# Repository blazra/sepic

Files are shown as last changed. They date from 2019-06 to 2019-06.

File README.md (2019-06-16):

# SEPIC
SEPIC converter design as a school project

Schematic: [kicad/sepic/sepic.pdf](kicad/sepic/sepic.pdf)  
Write-up in czech: [SEPIC_Radovan_Blazek.pdf](SEPIC_Radovan_Blazek.pdf)  
LibreOffice sheet with measured data: [Measurements.ods](Measurements.ods)  
LibreOffice sheet with component values calculations as per LT8710 datasheet: [SEPIC_calculations.ods](SEPIC_calculations.ods)  
LT8710 datasheet: https://www.analog.com/media/en/technical-documentation/data-sheets/8710f.pdf

Bugs in Rev. 1:
- SYNC input of the LT8710 is not pulled to GND

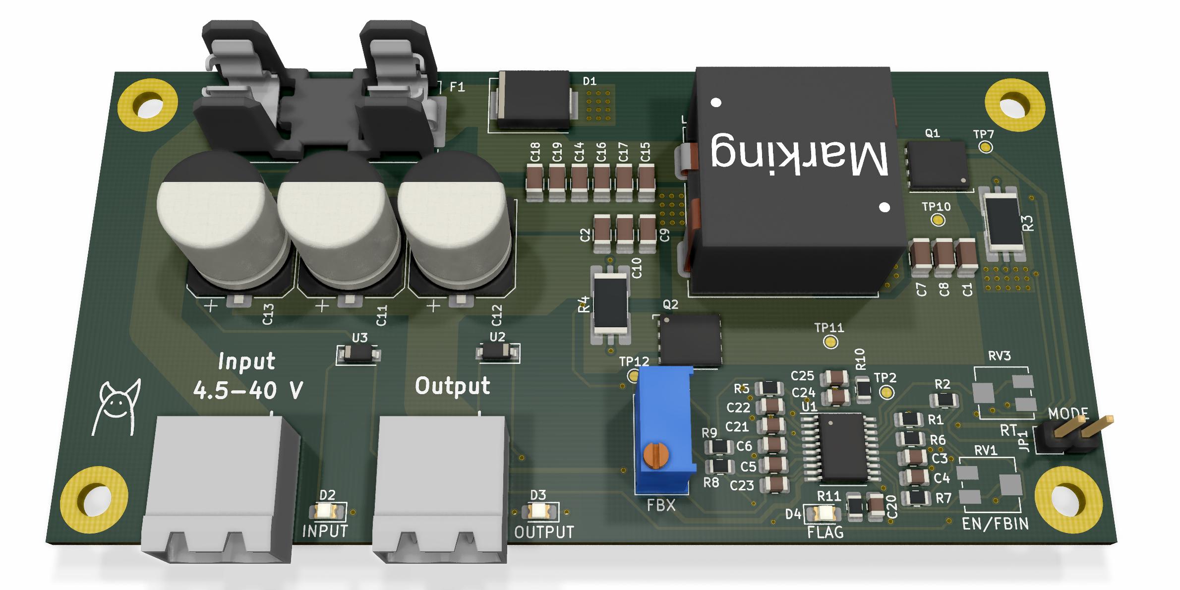
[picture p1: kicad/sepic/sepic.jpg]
3D render
3D render: 

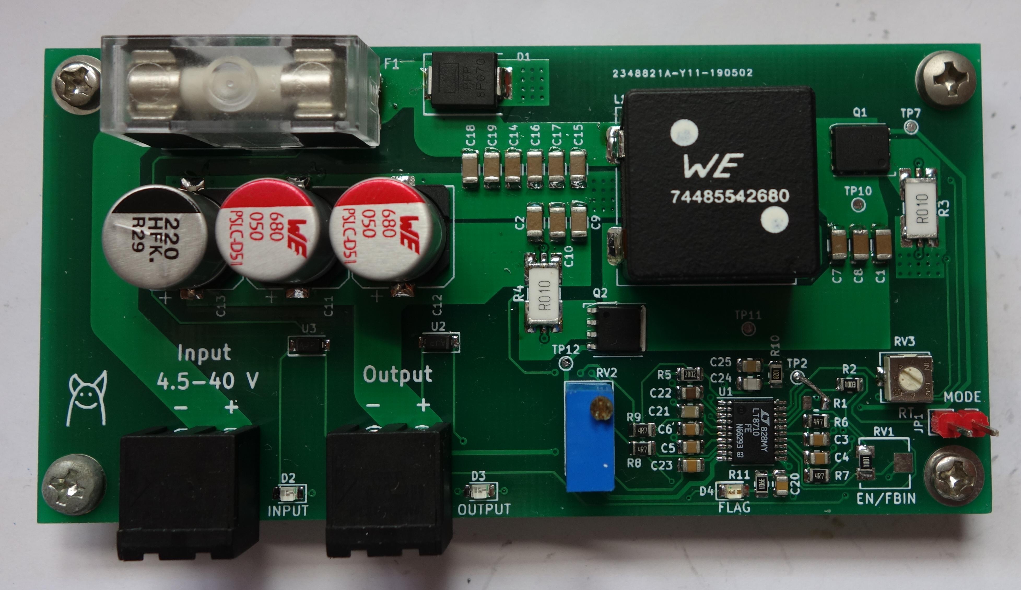
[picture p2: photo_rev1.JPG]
Photo of the finished board:

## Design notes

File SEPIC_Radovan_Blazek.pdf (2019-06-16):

# SEPIC

2019

## Radovan Blažek

## Semestrální práce na předmět B2M34VKE


## Obsah

1 Zadání | 2
2 Výpočet obvodových prvků | 2
3 Schéma | 2
4 Layout | 4
5 Měření | 5
6 Závěr | 7

## 1 Zadání

Navrhněte synchronní SEPIC, parametry: VIN = 6 V–28 V, VOUT = 15 V, POUT = 8W.

## 2 Výpočet obvodových prvků

Podle datasheetu řídícího obvodu LT8710: https://www.analog.com/media/en/technical-documentation/data-sheets/8710f.pdf

VIN(MIN) = 6 V
VOUT = 15 V
IOUT = 0.533 A
f = 500 kHz

DC MAX ≈

VOUT
VIN(MIN) + VOUT
; (Maximální střída) | DC MAX ≈ 0.714

VCSPN ≈ 37.5 mV ; (Určuje max. proud cívkou.)

RSENSE1 ≤ 0.58

VCSPN

IOUT

(1 − DC MAX) | RSENSE1 ≤ 0.0137 Ω → RSENSE1 = 10 mΩ

RSENSE2 ≤

0.05
1.6 · IOUT

RSENSE2 ≤ 0.0590 Ω → RSENSE2 = 10 mΩ

LTYP =

RSENSE1 · VOUT
12.5m · f

·

VIN(MIN)
VIN(MIN) + VOUT

LTYP = 6.86 µH

LMAX =

RSENSE1 · VOUT
40m · f

·

1 −

VIN(MIN)

VOUT 2

!
LMAX = 17.14 µH

LMIN =

RSENSE1 · VOUT
5m · f

·

VIN(MIN)
VIN(MIN) + VOUT

LMIN = 6.3 µH

C1 ≥ 10 µF

COUT ≥

IOUT · DCMAX
f · 0.005 · VOUT

COUT ≥ 10.1 µF

CIN ≥

DCMAX
8 · L · f

2 · 0.005

CIN ≥ 10.42 µF

CIMON ≥

100µ · DCMAX
0.005 · f

CIMON ≥ 28.57 nF

RFBX =

VOUT − 1.213 V
83.7 µA

RFBX = 164 719 Ω

RT =

35880
f
− 1 ; f in kHz and RT in kΩ | RT = 70.760 kΩ

## 3 Schéma

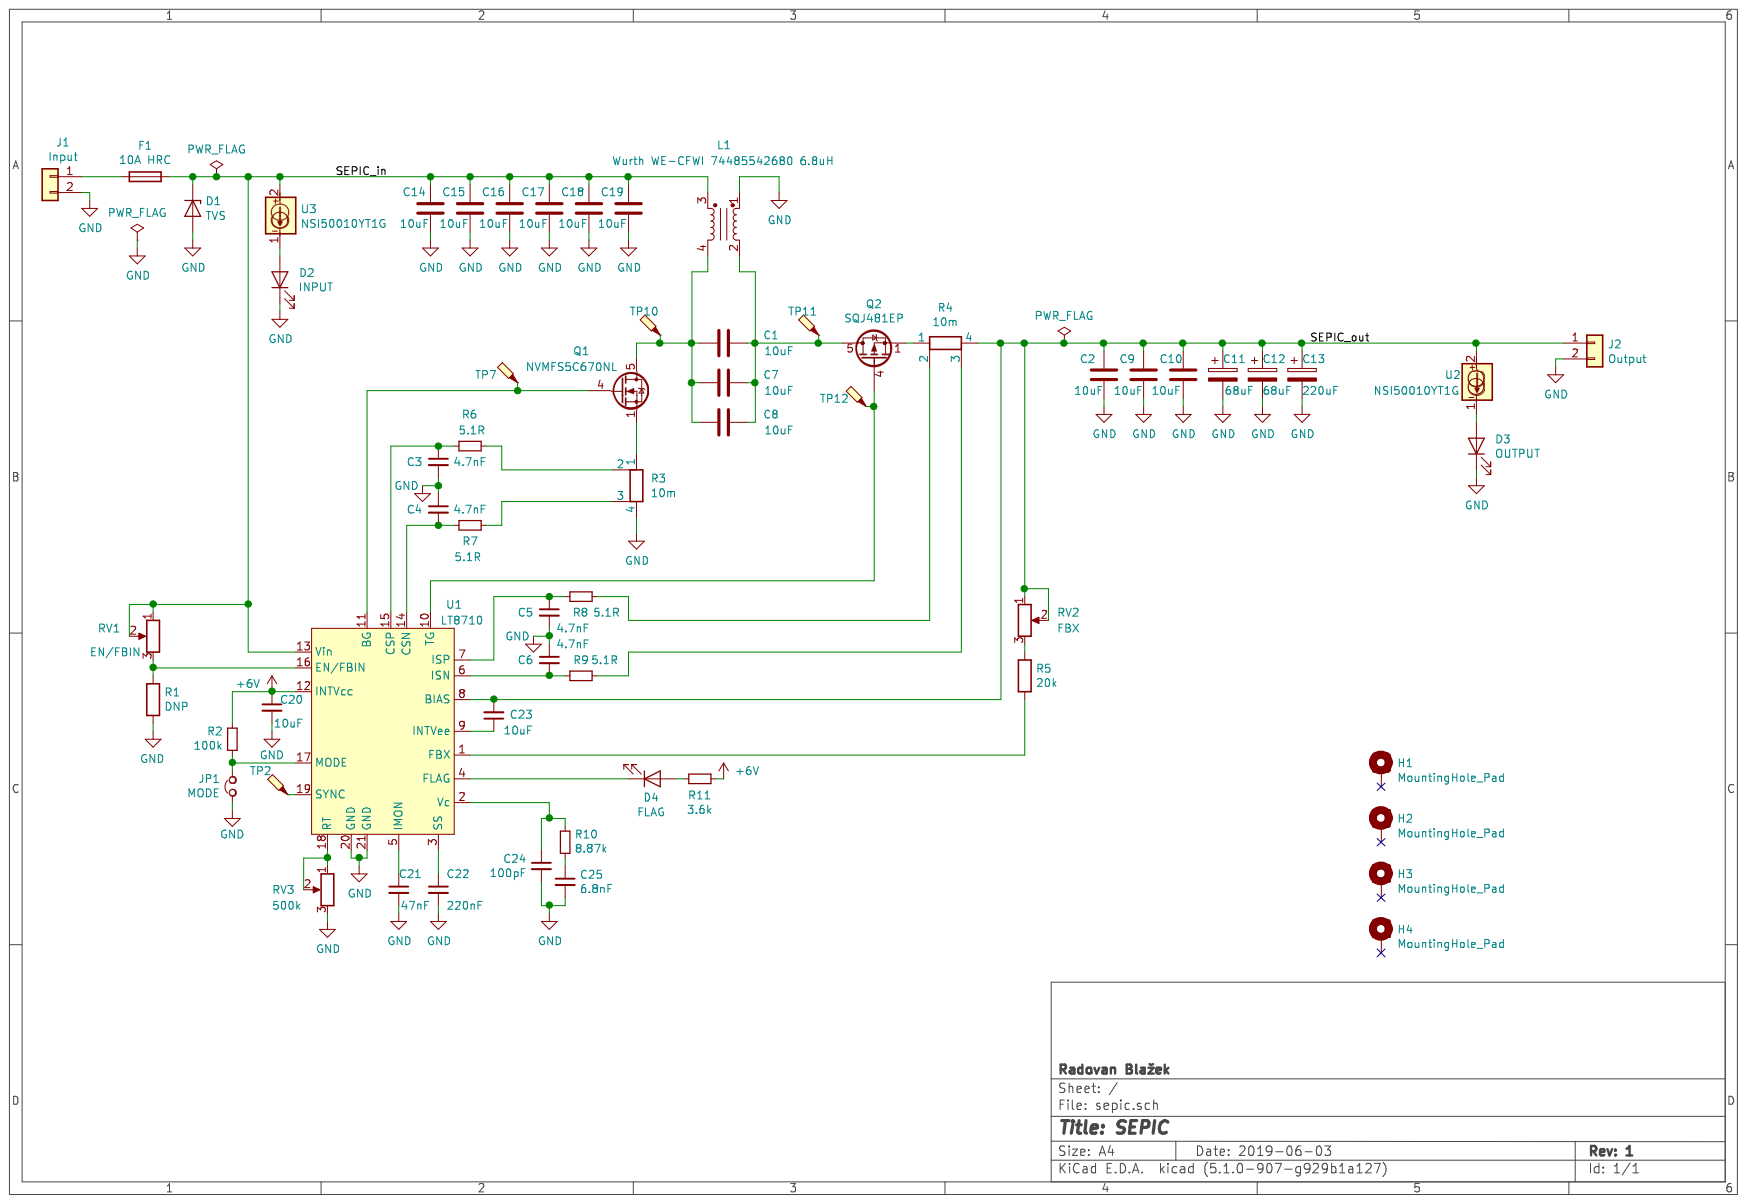
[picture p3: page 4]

## 4 Layout

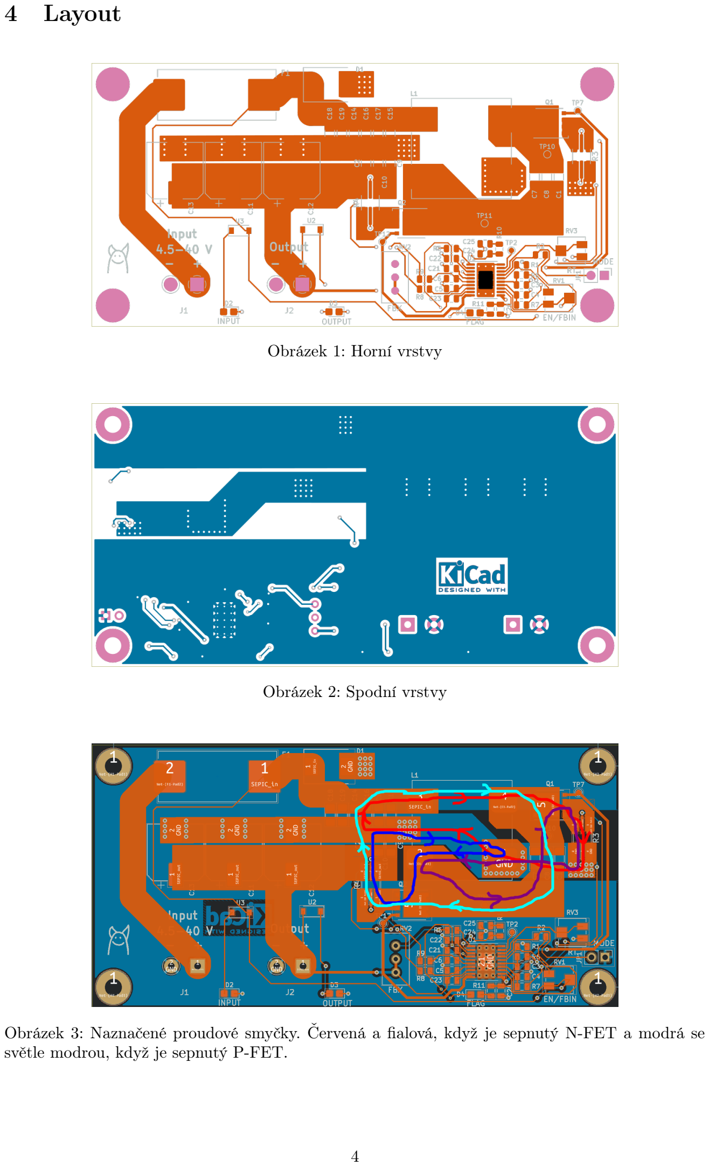
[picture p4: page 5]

Obrázek 1: Horní vrstvy

Obrázek 2: Spodní vrstvy

Obrázek 3: Naznačené proudové smyčky. Červená a fialová, když je sepnutý N-FET a modrá se světle modrou, když je sepnutý P-FET.

## 5 Měření

### 5.1 Použité přístroje

Zdroj | HP E3630 | (Vstupní napětí a proud do měniče)
Voltmetr | Keithley 2000 | (Výstupní napětí z měniče)
Elektronická zátěž | Chroma 63106 | (Výstupní proud z měniče)
Osciloskop | LeCroy WaveRunner 6050A | (Průběhy výstupního napětí)

### 5.2 Výsledky

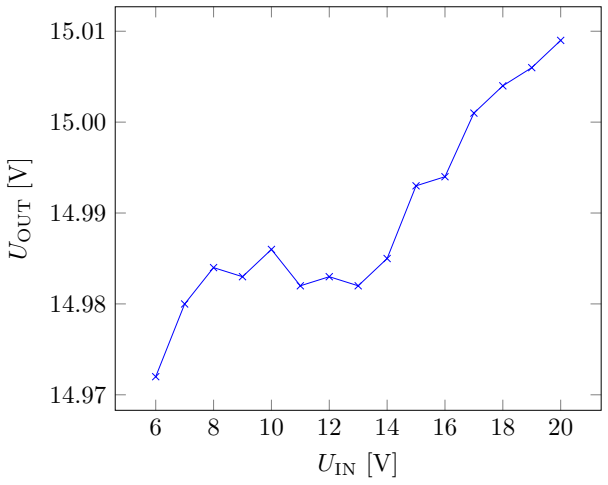
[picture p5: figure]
UIN [V]; UOUT [V]

Obrázek 4: Změna výstupního napětí v závislosti na vstupním napětí

LNR = 2.643 mV/V

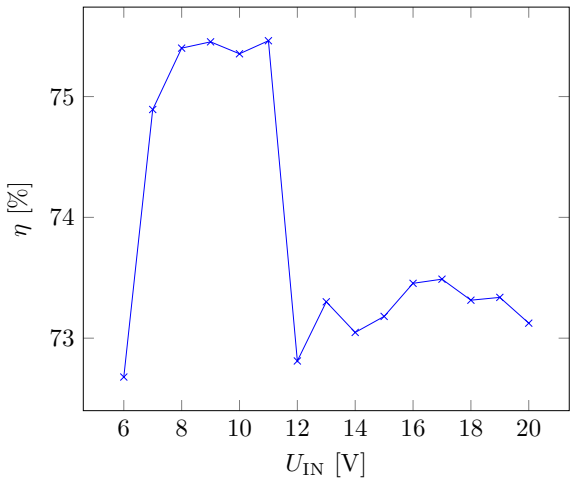
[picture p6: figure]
UIN [V]

Obrázek 5: Účinnost v závislosti na vstupním napětí

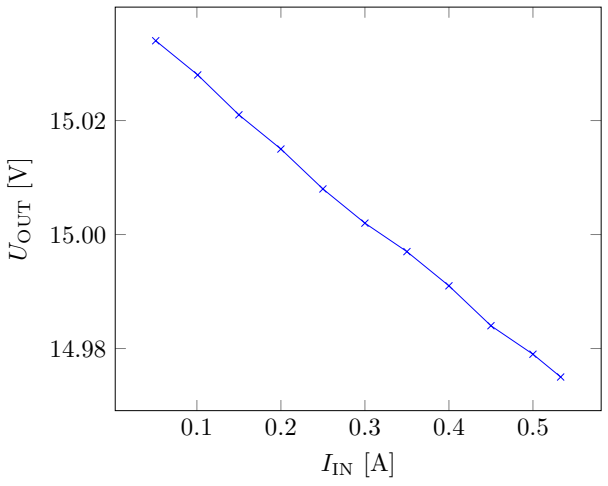
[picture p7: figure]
IIN [A]; UOUT [V]

Obrázek 6: Výstupní napětí v závislosti na výstupním proudu

LOR = −122.4 mV/A

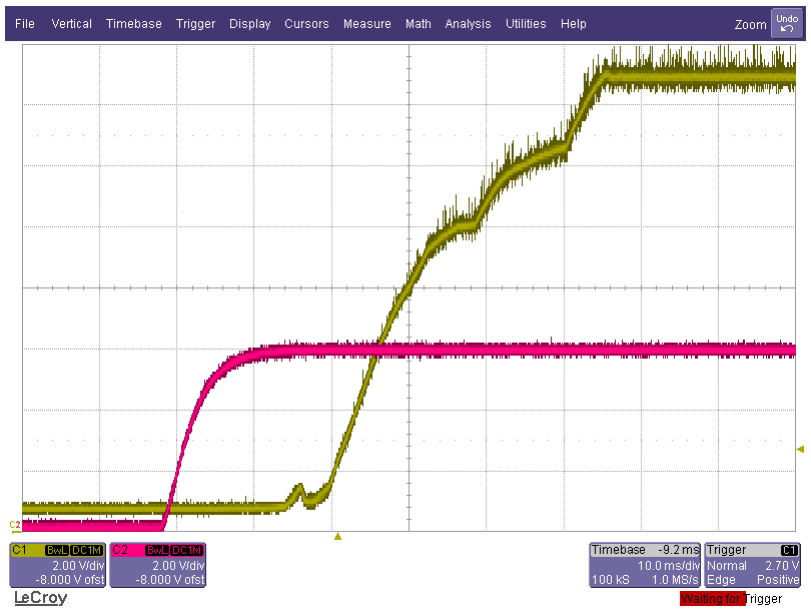
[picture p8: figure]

Obrázek 7: Start měniče. C2 (červená): vstup do měniče, C1 (žlutá): výstup z měniče. Nastavení osciloskopu: omezení šířky pásma na 20 MHz.

Na obrázku 8 je průběh výstupního napětí při skokové změně proudu do zátěže z 10 mA na 533 mA.

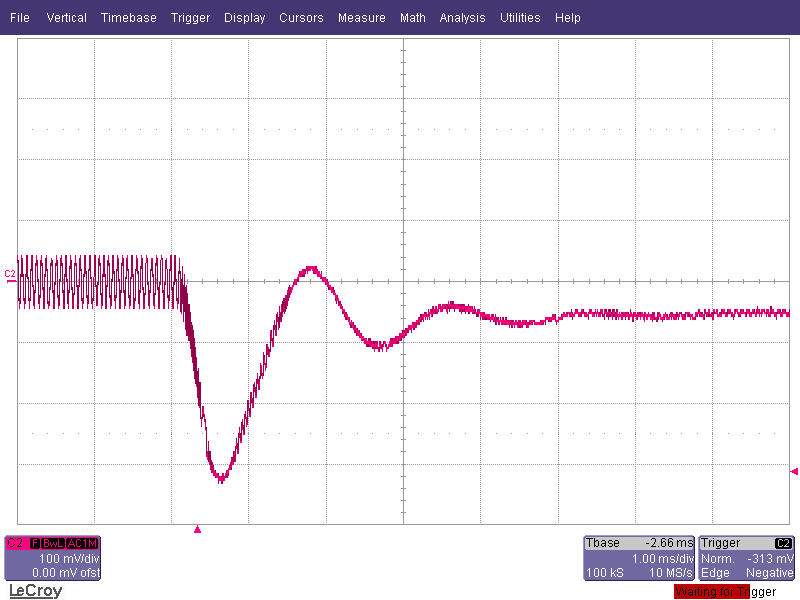
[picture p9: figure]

Obrázek 8: Odezva na skokovou změnu proudu do zátěže. Nastavení osciloskopu: omezení šířky pásma na 20 MHz a mód akvizice s vysokým rozlišením (oversampling).

## 6 Závěr

Částečné rozdělení zemní plochy byla rozhodně chyba, nicméně, nepodařilo se mi naměřit žádnou změnu v chování měniče při spojení všech částí zemní plochy v jednu souvislou.
Zásadní nedostatek je absence místa na PCB, kam by šla připojit proudová sonda na měření proudu cívkou.
Na výstupu měniče jsou veliké napěťové špičky vznikající při vypínání hlavního N-kanálového MOSFETu.
I přes zmíněné nedostatky měnič funguje a zvládá zatížení 8 W při vstupním napětí 6-20 V. Zadání bylo vstupní napětí až 28 V, ale při měření jsem měl k dispozici pouze zdroj do 20 V. Můj předpoklad je, že měnič by měl být funkční i v rozsahu 20-28 V.

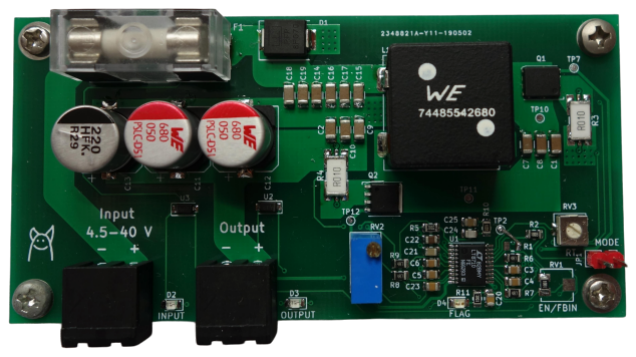
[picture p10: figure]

Obrázek 9: Fotografie osazeného desky měniče

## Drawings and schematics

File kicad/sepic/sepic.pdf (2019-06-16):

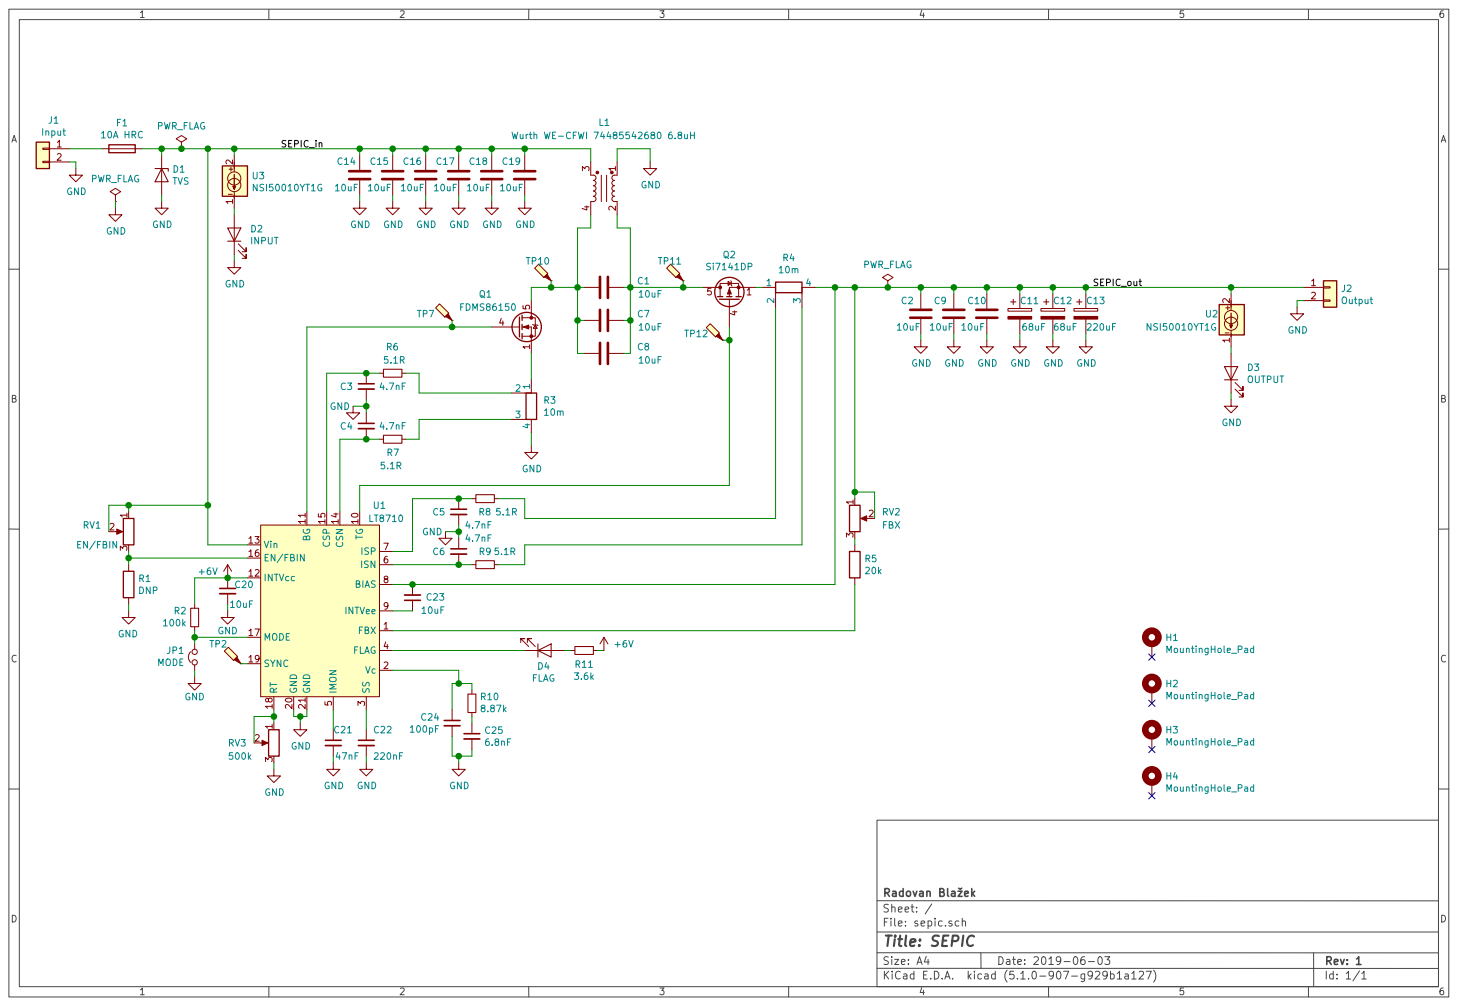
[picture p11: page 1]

File: sepic.sch Sheet: / Radovan Blaek GND

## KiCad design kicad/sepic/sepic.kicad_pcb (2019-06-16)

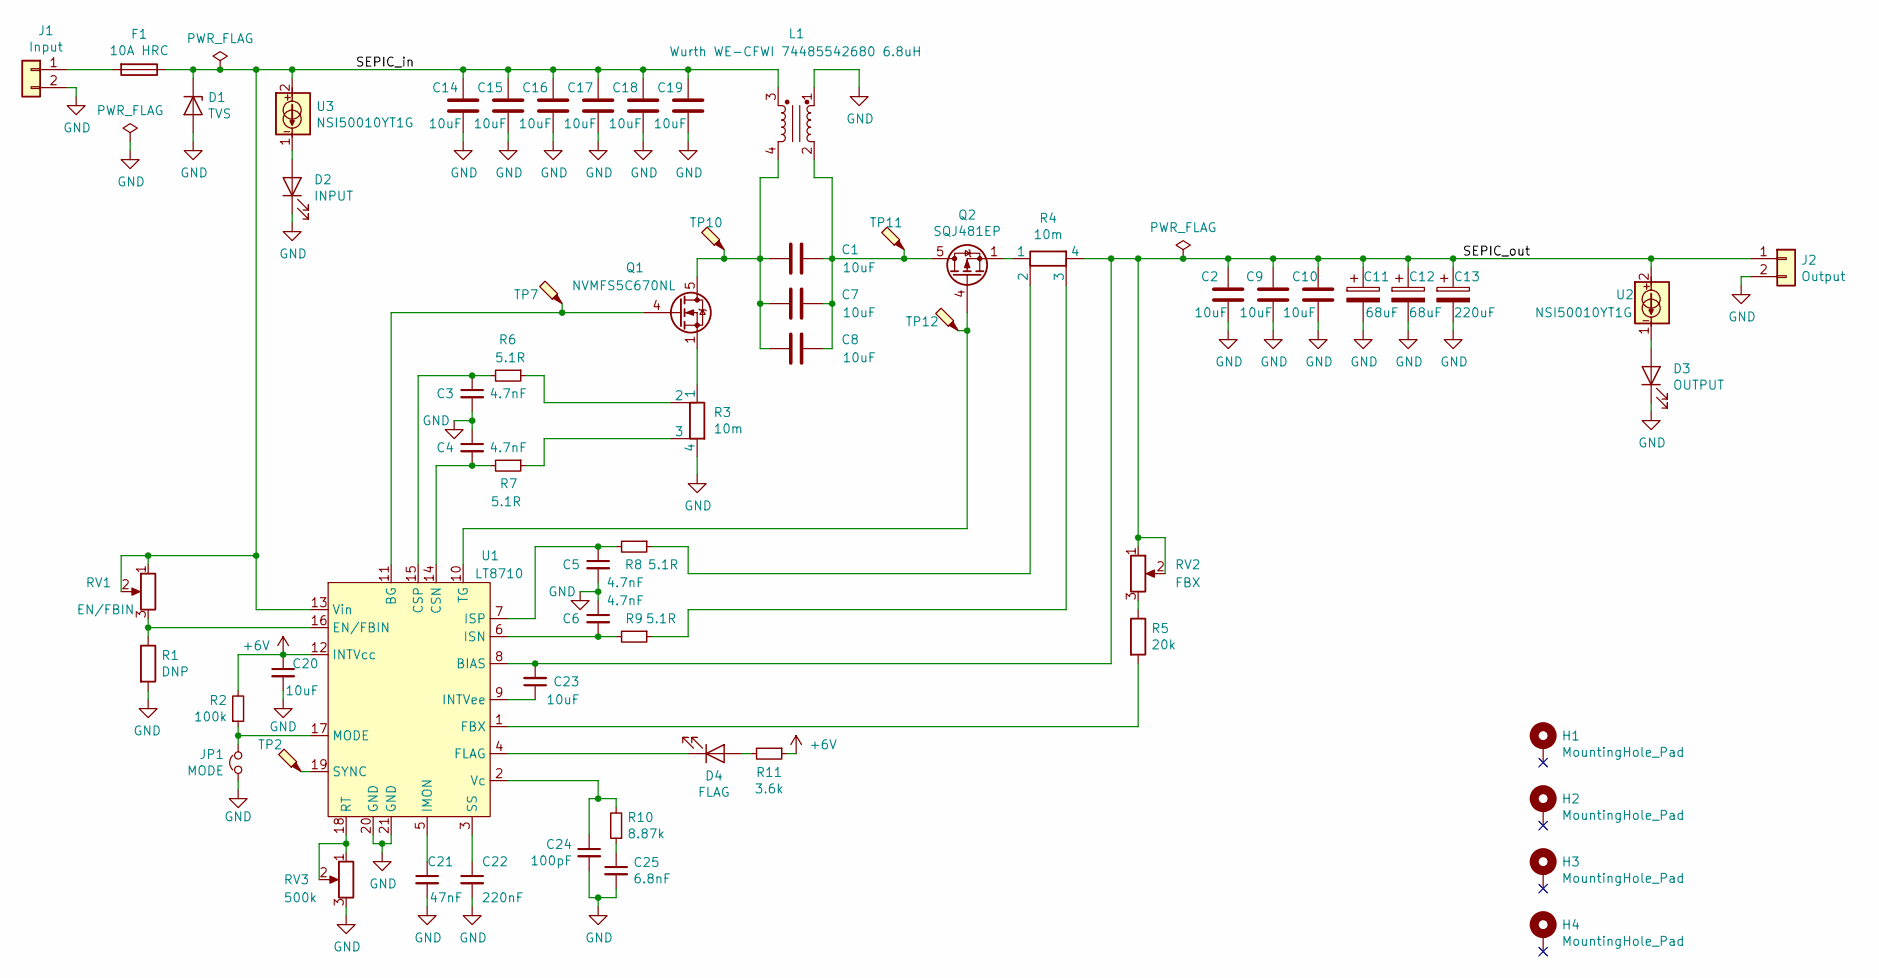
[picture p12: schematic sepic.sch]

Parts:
C1, C2, C7, C8, C9, C10, C14, C15, C16, C17, C18, C19: 10uF; C_1206_3216Metric
C3, C4, C5, C6: 4.7nF; C_0805_2012Metric
C11, C12: 68uF; CP_Elec_10x12.5
C13: 220uF; CP_Elec_10x12.5
C20, C23: 10uF; C_0805_2012Metric
C21: 47nF; C_0805_2012Metric
C22: 220nF; C_0805_2012Metric
C24: 100pF; C_0805_2012Metric
C25: 6.8nF; C_0805_2012Metric
D1: TVS; D_SMC
D2: INPUT; LED_0805_2012Metric_Castellated
D3: OUTPUT; LED_0805_2012Metric_Castellated
D4: FLAG; LED_0805_2012Metric_Castellated
F1: 10A HRC; Fuseholder_Cylinder-5x20mm_Schurter_OGN-SMD_Horizontal_Open
H1, H2, H3, H4: MountingHole_Pad; MountingHole_3.2mm_M3_Pad
J1: Input; TerminalBlock_PTR_P5.00mm_Horizontal
J2: Output; TerminalBlock_PTR_P5.00mm_Horizontal
JP1: MODE; PinHeader_1x02_P2.54mm_Vertical
L1: Wurth WE-CFWI 74485542680 6.8uH; Wurth_WE-CFWI_1813
Q1: NVMFS5C670NL; TDSON-8-1
Q2: SQJ481EP; TDSON-8-1
R1: DNP; R_0805_2012Metric
R2: 100k; R_0805_2012Metric
R3, R4: 10m; R_2512_6332Metric
R5: 20k; R_0805_2012Metric
R6, R7, R8, R9: 5.1R; R_0805_2012Metric
R10: 8.87k; R_0805_2012Metric
R11: 3.6k; R_0805_2012Metric
RV1: EN/FBIN; Potentiometer_Vishay_TS53YJ_Vertical
RV2: FBX; Potentiometer_Bourns_3296W_Vertical
RV3: 500k; Potentiometer_Vishay_TS53YJ_Vertical
TP2, TP7, TP10, TP11, TP12: TEST_POINT; TestPoint_Pad_D1.0mm
U1: LT8710; HTSSOP-20-1EP_4.4x6.5mm_P0.65mm_EP3.4x6.5mm_Mask2.75x3.43mm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
U2, U3: NSI50010YT1G; D_SOD-123

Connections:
+6V: C20.1, R2.2, R11.1, U1.12 (INTVcc)
/SEPIC_in: C14.2, C15.2, C16.2, C17.2, C18.2, C19.2, D1.1 (K), F1.1, L1.3, RV1.1, RV1.2, U1.13 (Vin), U3.2
/SEPIC_out: C2.1, C9.1, C10.1, C11.1, C12.1, C13.1, C23.2, J2.1, R4.4, RV2.1, RV2.2, U1.8 (BIAS), U2.2
GND: C2.2, C3.2, C4.1, C5.2, C6.1, C9.2, C10.2, C11.2, C12.2, C13.2, C14.1, C15.1, C16.1, C17.1, C18.1, C19.1, C20.2, C21.2, C22.2, C24.2, C25.2, D1.2 (A), D2.1 (K), D3.1 (K), J1.2, J2.2, JP1.1, L1.1, R1.2, R3.4, RV3.3, U1.20 (GND), U1.21 (GND)
unnamed: C1.1, C7.1, C8.1, L1.2, Q2.5 (D), TP11.1
unnamed: C1.2, C7.2, C8.2, L1.4, Q1.5 (D), TP10.1
unnamed: C3.1, R6.2, U1.15 (CSP)
unnamed: C4.2, R7.2, U1.14 (CSN)
unnamed: C5.1, R8.2, U1.7 (ISP)
unnamed: C6.2, R9.2, U1.6 (ISN)
unnamed: C21.1, U1.5 (IMON)
unnamed: C22.1, U1.3 (SS)
unnamed: C23.1, U1.9 (INTVee)
unnamed: C24.1, R10.2, U1.2 (Vc)
unnamed: C25.1, R10.1
unnamed: D2.2 (A), U3.1
unnamed: D3.2 (A), U2.1
unnamed: D4.1 (K), U1.4 (FLAG)
unnamed: D4.2 (A), R11.2
unnamed: F1.2, J1.1
unnamed: JP1.2, R2.1, U1.17 (MODE)
unnamed: Q1.1 (S), Q1.2 (S), Q1.3 (S), R3.1
unnamed: Q1.4 (G), TP7.1, U1.11 (BG)
unnamed: Q2.1 (S), Q2.2 (S), Q2.3 (S), R4.1
unnamed: Q2.4 (G), TP12.1, U1.10 (TG)
unnamed: R1.1, RV1.3, U1.16 (EN/FBIN)
unnamed: R5.1, RV2.3
unnamed: R5.2, U1.1 (FBX)
unnamed: R3.2, R6.1
unnamed: R3.3, R7.1
unnamed: R4.2, R8.1
unnamed: R4.3, R9.1
unnamed: RV3.1, RV3.2, U1.18 (RT)
unnamed: TP2.1, U1.19 (SYNC)

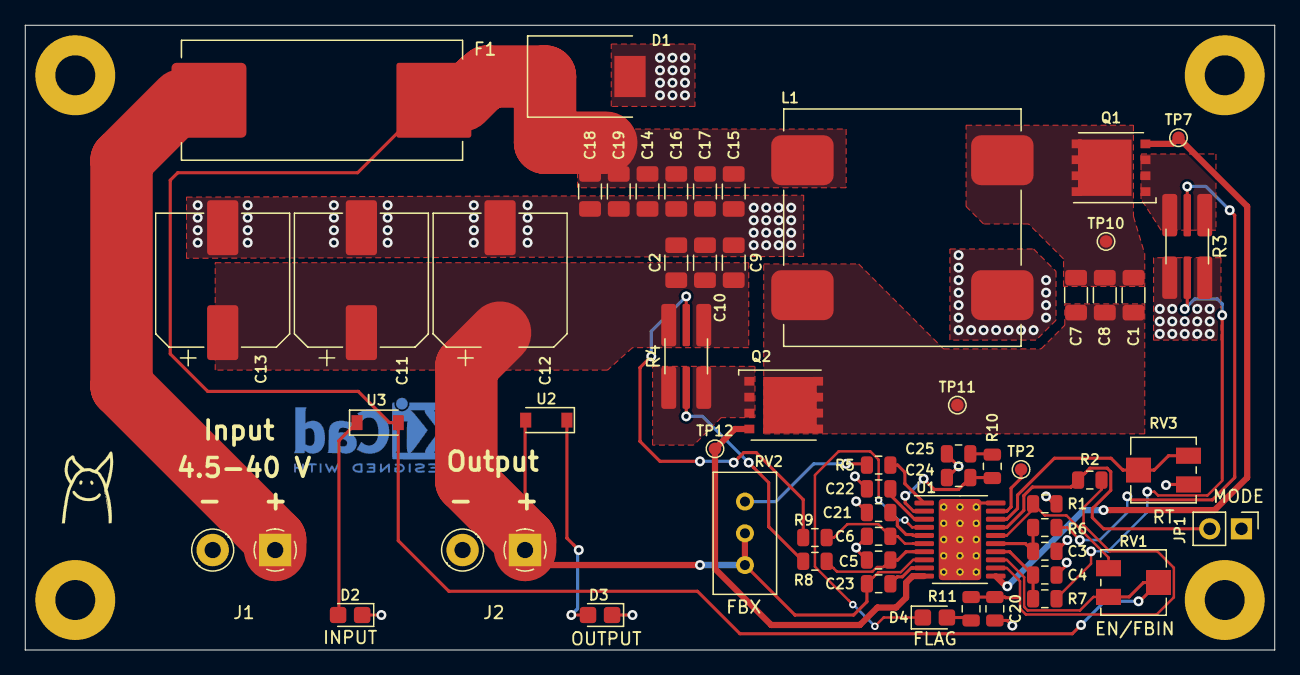
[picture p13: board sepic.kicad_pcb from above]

Board: 2 copper layers, 100.0 x 50.0 mm, 62 parts (0 on the bottom side), 34 nets.

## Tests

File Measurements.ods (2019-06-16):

Uin | Iin | Pin | Uout | Iout | Pout | n | LNR [mV/V]
6 | 1,83 | 10,98 | 14,972 | 0,533 | 7,980076 | 72,6782877959927 | 2,6428571428572
7 | 1,523 | 10,661 | 14,98 | 0,533 | 7,98434 | 74,8929743926461
8 | 1,324 | 10,592 | 14,984 | 0,533 | 7,986472 | 75,4009818731118
9 | 1,176 | 10,584 | 14,983 | 0,533 | 7,985939 | 75,4529383975813
10 | 1,06 | 10,6 | 14,986 | 0,533 | 7,987538 | 75,3541320754717
11 | 0,962 | 10,582 | 14,982 | 0,533 | 7,985406 | 75,4621621621622
12 | 0,914 | 10,968 | 14,983 | 0,533 | 7,985939 | 72,8112600291758
13 | 0,838 | 10,894 | 14,982 | 0,533 | 7,985406 | 73,3009546539379
14 | 0,781 | 10,934 | 14,985 | 0,533 | 7,987005 | 73,0474208889702
15 | 0,728 | 10,92 | 14,993 | 0,533 | 7,991269 | 73,1801190476191
16 | 0,68 | 10,88 | 14,994 | 0,533 | 7,991802 | 73,4540625
17 | 0,64 | 10,88 | 15,001 | 0,533 | 7,995533 | 73,4883547794118
18 | 0,606 | 10,908 | 15,004 | 0,533 | 7,997132 | 73,3143747708104
19 | 0,574 | 10,906 | 15,006 | 0,533 | 7,998198 | 73,3375939849624
20 | 0,547 | 10,94 | 15,009 | 0,533 | 7,999797 | 73,1242870201097
Load Reg
Uin | Iout | Uout | LOR [mV/A]
6 | 0,051 | 15,034 | -122,406639004152
 | 0,101 | 15,028
 | 0,15 | 15,021
 | 0,2 | 15,015
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
